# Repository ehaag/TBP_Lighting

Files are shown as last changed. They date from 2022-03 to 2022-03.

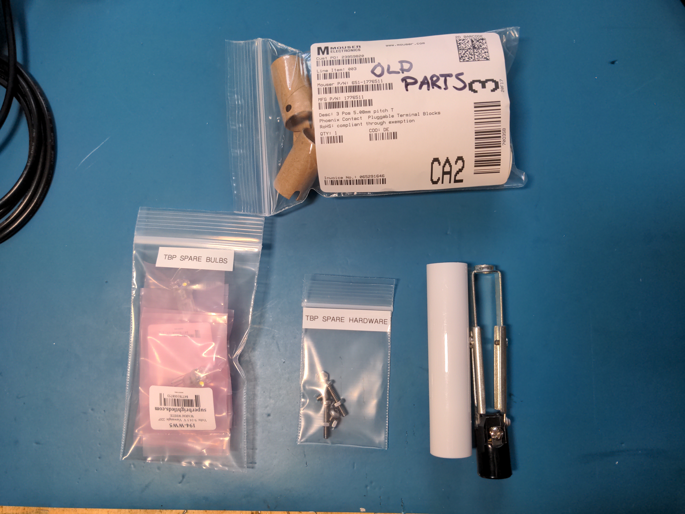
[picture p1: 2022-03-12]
img/Acc_PartsBags.jpg

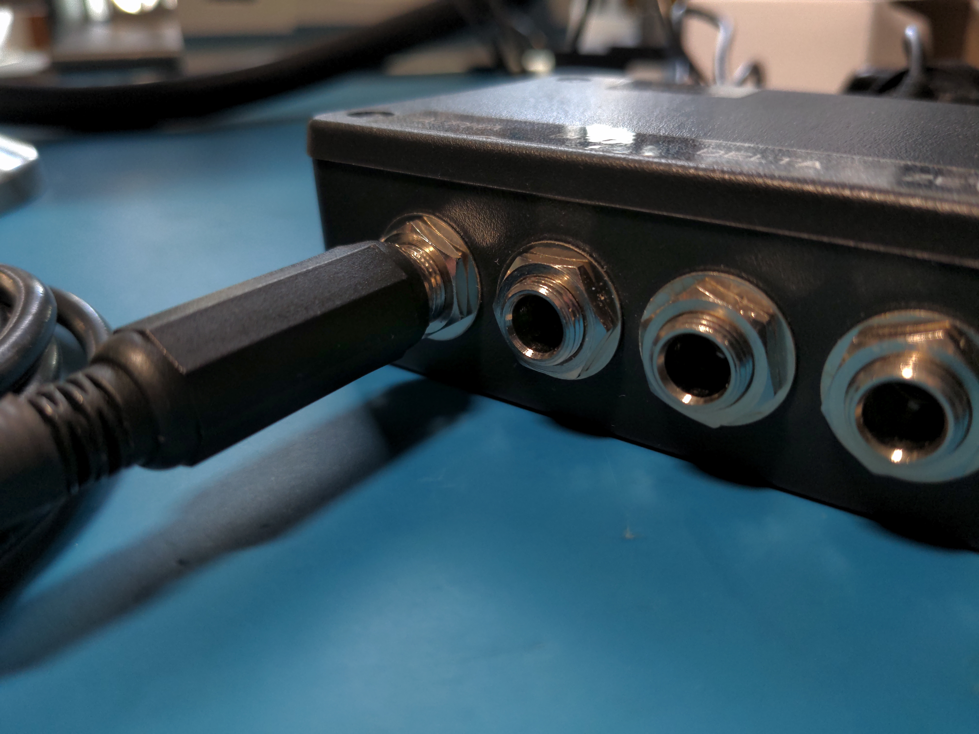
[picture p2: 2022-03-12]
img/Ctrl_LampPlugged.jpg

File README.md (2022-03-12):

# TBP_Lighting
**Ceremony lighting for Tau Beta Pi**

This repo holds the documentation for the Tau Beta Pi ceremony lighting revamp created by Erik Haag in Fall 2021. The main purpose of the project was to modernize some of the less-than-savory, officially sponsored hacks that were used to make the original system "safe". Main highlights include:
  * Moving from a mains-powered incandescent lamp to an LED lamp powered from low voltage DC
  * Improving the durability of the system through improved connectors, strain reliefs, and other parts
  * Custom PCB including overvoltage, reverse voltage, and overcurrent protection

The content here consists primarily of two sections. First, the user manual (i.e., the Wiki in the tab above) contains the basic information needed to operate the lighting system. Honestly, it's really pretty simple. There are lots of pictures. Don't be afraid. The other section pertains to the custom PCB that was designed for this project. It includes a schematic, a bill of materials, an assembly drawing, the KiCad project files, and the Gerbers for the board itself.

Finally, for any questions or concerns not explicitly addressed by the documents contained in this repository, please feel free to use the issue tracker associated with this repository. I have also included my U of M email address on the inside of the control unit's cover, in case I happen to miss anything here.

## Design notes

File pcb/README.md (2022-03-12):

PDFs provided for the protection board schematic and assembly drawing. CAD directory holds all design files. See the [Wiki](https://github.com/ehaag/TBP_Lighting/wiki/Home).

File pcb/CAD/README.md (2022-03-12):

CAD files for the protection board. Please see the associated [Wiki page](https://github.com/ehaag/TBP_Lighting/wiki/CAD).

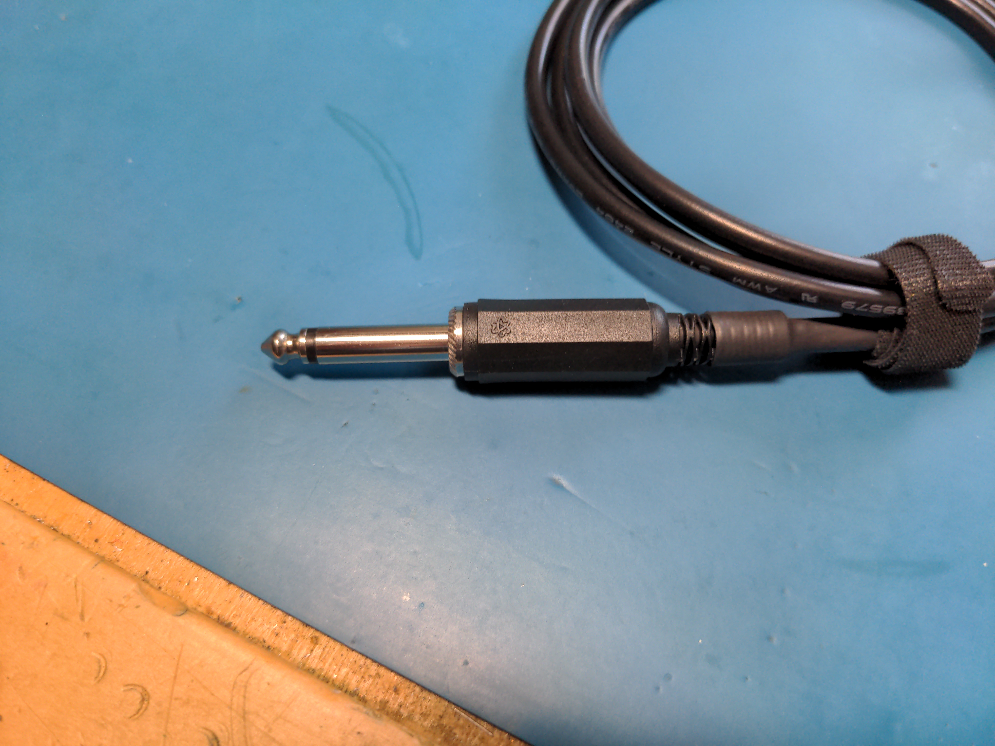
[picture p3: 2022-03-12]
img/Lamp_Plug.jpg

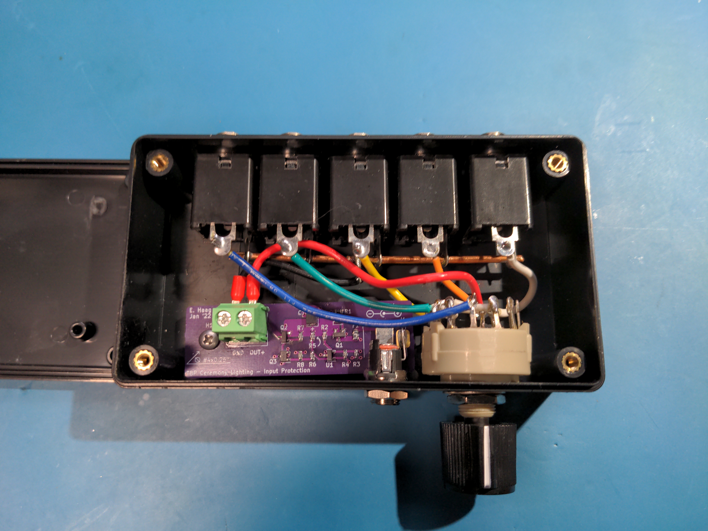
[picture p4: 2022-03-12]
img/Ctrl_OpenTop.jpg

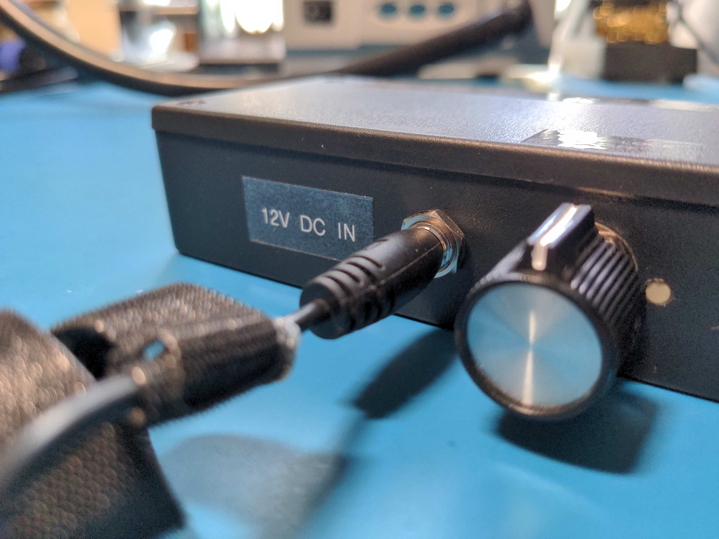
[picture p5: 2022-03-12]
img/Ctrl_DCPlugged.jpg

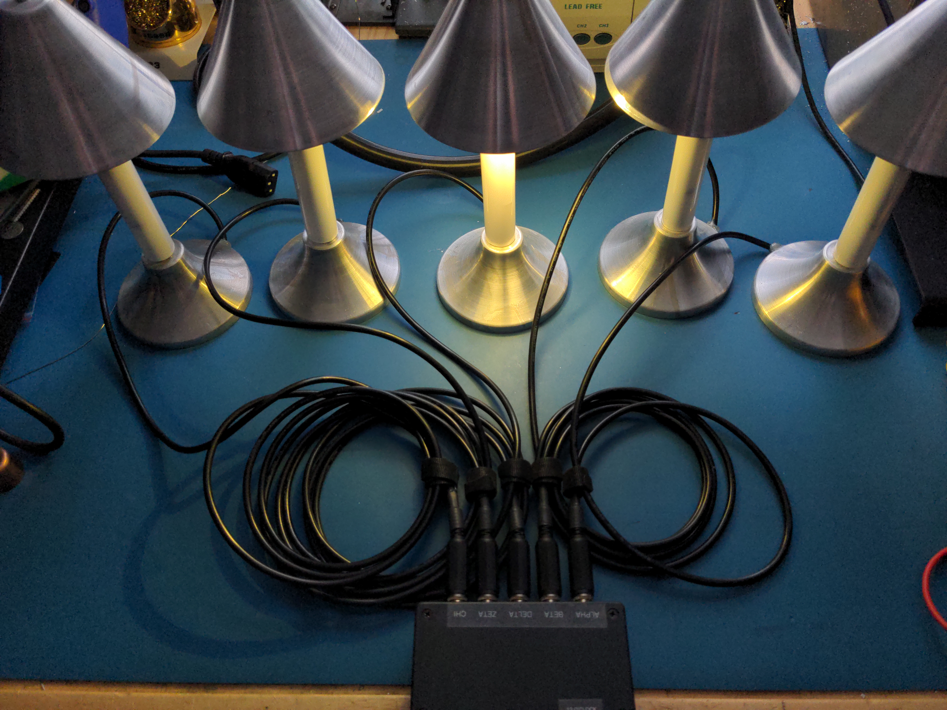
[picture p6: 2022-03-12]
img/Seq_Posn4.jpg

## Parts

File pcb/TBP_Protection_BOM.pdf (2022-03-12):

TBP_Protection

Page 1

Reference | Value | Manufacturer | Description | Footprint | Datasheet

# Protection Board Parts

C1 | 10u | Various | Tantalum polymer capacitor, 25V | Capacitor_Tantalum_SMD:CP_EIA-3528-12_Kemet-T | Generic
D1 | | Nexperia | Zener diode, 16V | Diode_SMD:D_SOD-323F | https://assets.nexperia.com/documents/data-sheet/PZUXB_SER.pdf
F1 | | Littelfuse | PTC fuse, 100mA | Fuse:Fuse_0805_2012Metric | https://www.littelfuse.com/~/media/electronics/datasheets/resettable_ptcs/littelfuse_ptc_0805l_datasheet.pdf.pdf
J1 | PJ-066B | CUI | 2.5x5.5mm DC barrel jack, panel mount | user_Connector:BarrelJack_CUI_PJ-066 | https://www.cuidevices.com/product/resource/pj-066a.pdf
J2 | MKDS | Phoenix Contact | MPN 1711725, 5.08mm, 2 position terminal block | TerminalBlock_Phoenix:TerminalBlock_Phoenix_MKDS-1,5-2-5.08_1x02_P5.08mm_Horizontal | https://media.digikey.com/pdf/Data%20Sheets/Phoenix%20Contact%20PDFs/1711725.pdf
Q1, Q2 | Si2369DS | Vishay | 30V P-channel MOSFET | Package_TO_SOT_SMD:SOT-23 | http://www.vishay.com/docs/62865/si2369d.pdf
Q3 | AO3404A | Alpha Omega Semi | 30V N-channel MOSFET | Package_TO_SOT_SMD:SOT-23 | http://aosmd.com/pdfs/datasheet/AO3404A.pdf
R1 | 100k | Various | Metal film resistor, 1% tolerance, 100ppm/degC | Resistor_SMD:R_0603_1608Metric | Generic
R2 | 33k | Various | Metal film resistor, 1% tolerance, 100ppm/degC | Resistor_SMD:R_0603_1608Metric | Generic
R3 | 6k8 | Various | Metal film resistor, 1% tolerance, 100ppm/degC | Resistor_SMD:R_0603_1608Metric | Generic
R4 | 330k | Various | Metal film resistor, 1% tolerance, 100ppm/degC | Resistor_SMD:R_0603_1608Metric | Generic
R5, R7 | 10k | Various | Metal film resistor, 1% tolerance, 100ppm/degC | Resistor_SMD:R_0603_1608Metric | Generic
R6 | 47k | Various | Metal film resistor, 1% tolerance, 100ppm/degC | Resistor_SMD:R_0603_1608Metric | Generic
R8 | 27k | Various | Metal film resistor, 1% tolerance, 100ppm/degC | Resistor_SMD:R_0603_1608Metric | Generic
U1 | ATL431DBZ | Texas Instruments | Adjustable voltage reference | Package_TO_SOT_SMD:SOT-23 | http://www.ti.com/lit/ds/symlink/atl431.pdf

# Other Control Unit Parts

| 111x | Switchcraft | ¼” mono jack, panel mount | N/A | https://www.switchcraft.com/Drawings/110x-m110x_series_cd.pdf
| 16-00031 | Tensility | 12V, 6W, AC-DC wall adapter | N/A | http://www.tensility.com/pdffiles/16-00031.pdf
| 1591XXBBK | Hammond | Black ABS project box | N/A | http://www.hammondmfg.com/pdf/1591XXB.pdf
| KC52A13.001NLS | E-Switch | 12 position rotary switch, single pole | N/A | https://sten-eswitch-13110800-production.s3.amazonaws.com/system/asset/product_line/data_sheet/105/KC.pdf

# Lamp Parts

| 4833.1210 | Schurter | ¼” mono plug, free hanging | N/A | https://www.schurter.com/en/datasheet/typ_4833.1210.pdf
| 30-00686 | Tensility | 20 AWG, 2 conductor cable | N/A | http://www.tensility.com/pdffiles/30-00686.pdf
| T3.25-SW | SuperBrightLEDs | T3.25 wedge base socket, wired | N/A | https://www.superbrightleds.com/moreinfo/vehicle-bulb-sockets-adapters/t325-wedge-base-socket-wired/1150/2737/
| 194-WW5 | SuperBrightLEDs | Miniature wedge, 30 lumens, warm white | N/A | https://www.superbrightleds.com/moreinfo/miniature-and-subminiature-bulbs/194-led-landscape-light-bulb-5-led-miniature-wedge-retrofit-30-lumens/3308/9892/

PZU16B2

0805L010/24YR

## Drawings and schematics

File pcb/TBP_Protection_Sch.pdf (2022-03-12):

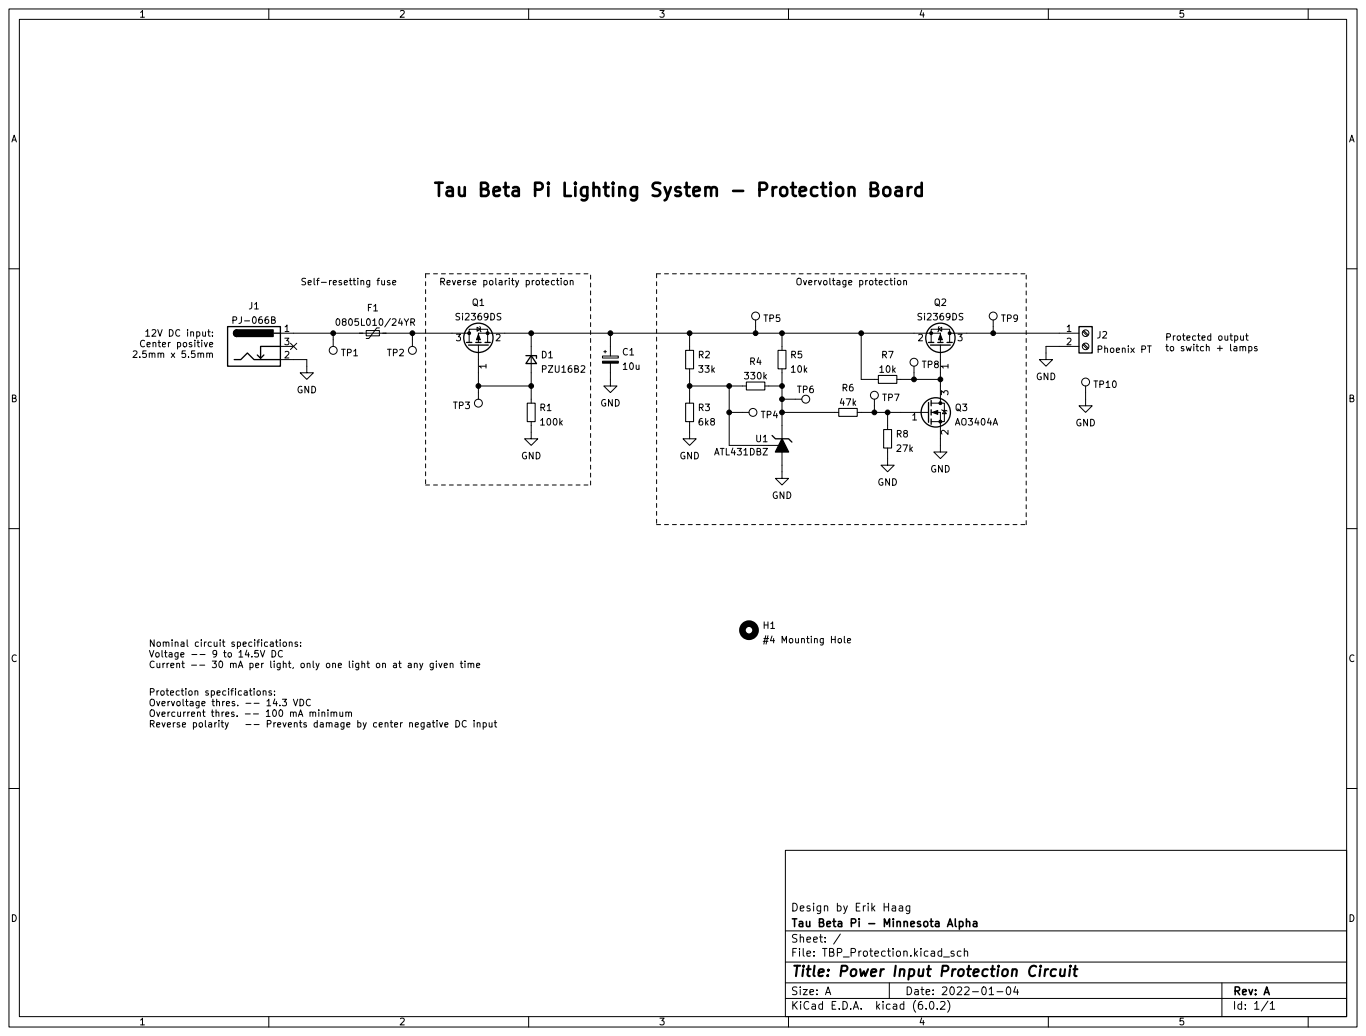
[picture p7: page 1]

Tau Beta Pi Lighting System - Protection Board

Nominal circuit specifications:
Voltage -- 9 to 14.5V DC
Current -- 30 mA per light, only one light on at any given time

Protection specifications:
Overvoltage thres. -- 14.3 VDC Overcurrent thres. -- 100 mA minimum

Reverse polarity -- Prevents damage by center negative DC input

File: TBP_Protection.kicad_sch Sheet: / Tau Beta Pi - Minnesota Alpha

Id: 1/1 Title: Power Input Protection Circuit

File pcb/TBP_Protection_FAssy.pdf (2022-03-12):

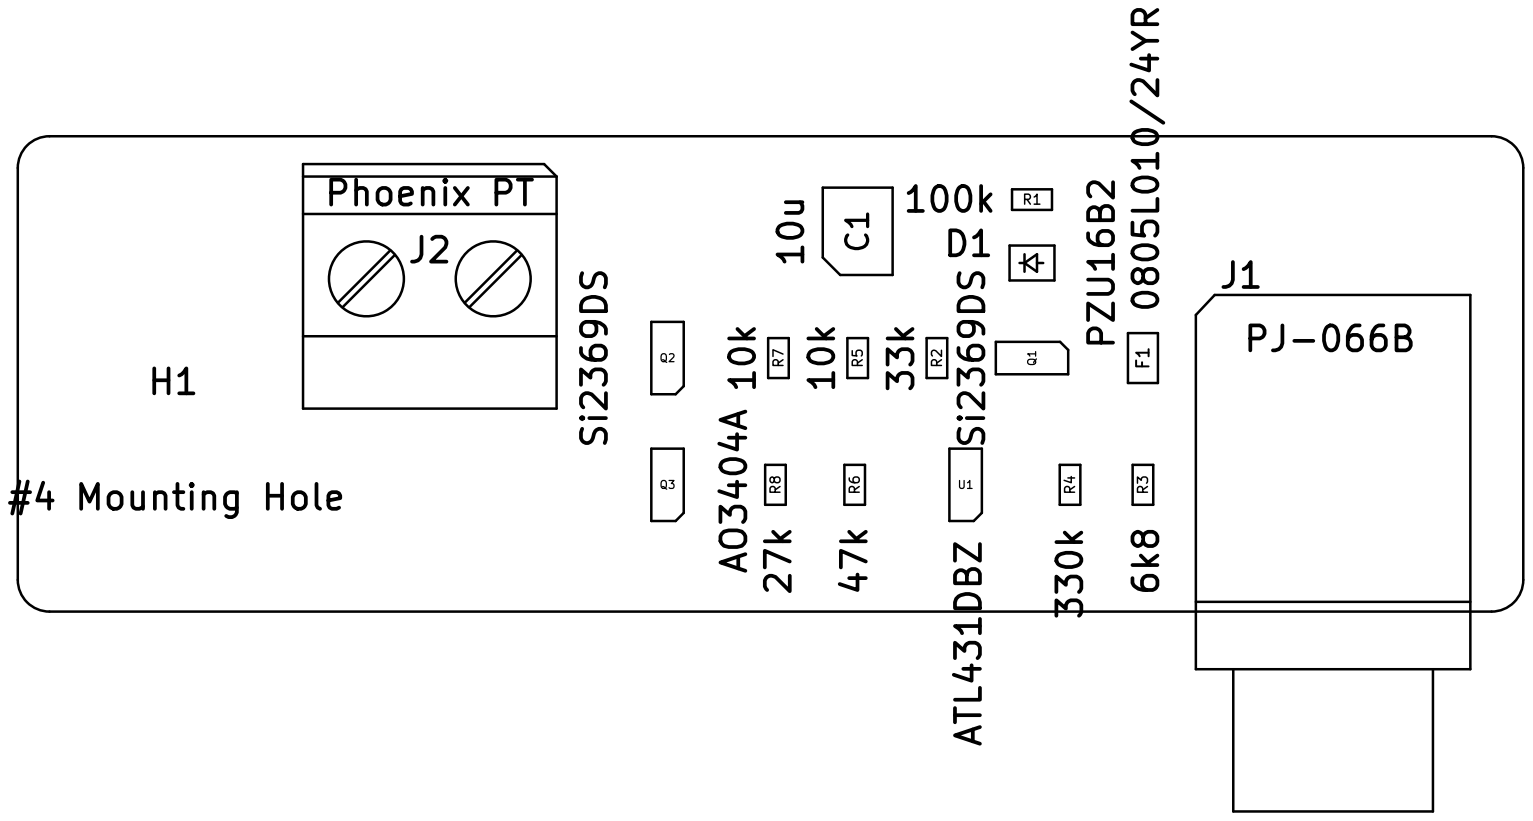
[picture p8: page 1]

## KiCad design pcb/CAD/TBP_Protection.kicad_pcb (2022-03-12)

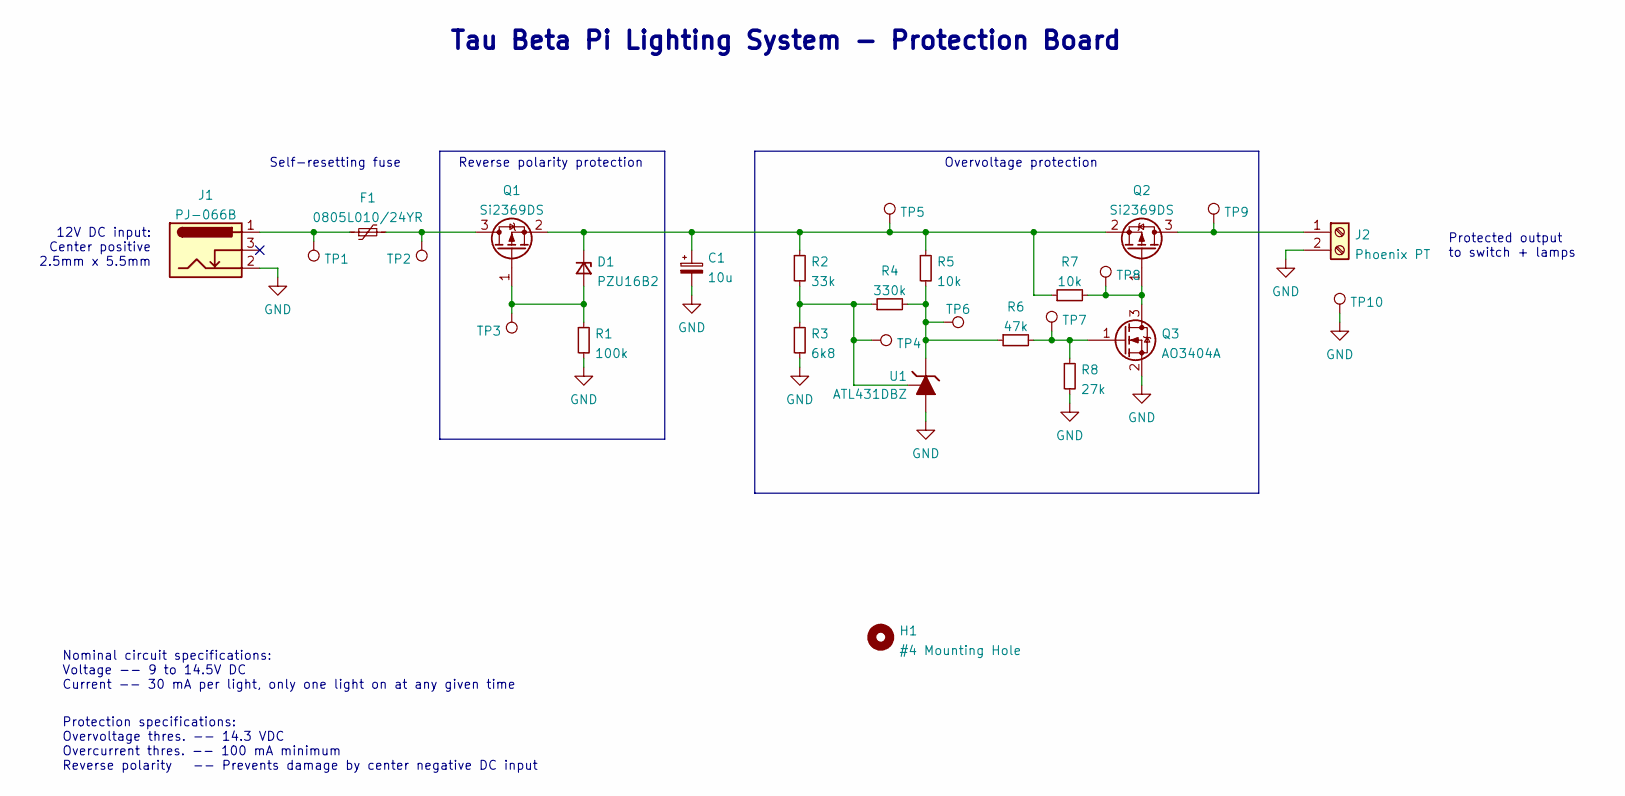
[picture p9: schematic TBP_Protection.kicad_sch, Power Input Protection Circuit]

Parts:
C1: 10u; CP_EIA-3528-12_Kemet-T
D1: ‎PZU16B2; D_SOD-323F
F1: ‎0805L010/24YR‎; Fuse_0805_2012Metric
H1: #4 Mounting Hole; MountingHole_3.5mm
J1: PJ-066B; BarrelJack_CUI_PJ-066A
J2: Phoenix PT; TerminalBlock_Phoenix_MKDS-1,5-2-5.08_1x02_P5.08mm_Horizont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
Q1, Q2: Si2369DS; SOT-23
Q3: AO3404A; SOT-23
R1: 100k; R_0603_1608Metric
R2: 33k; R_0603_1608Metric
R3: 6k8; R_0603_1608Metric
R4: 330k; R_0603_1608Metric
R5, R7: 10k; R_0603_1608Metric
R6: 47k; R_0603_1608Metric
R8: 27k; R_0603_1608Metric
TP1, TP2, TP3, TP4, TP5, TP6, TP7, TP8, TP9, TP10: TestPoint_Small; TestPoint_Pad_D1.5mm
U1: ATL431DBZ; SOT-23

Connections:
GND: C1.2, J1.2, J2.2, Q3.2 (S), R1.2, R3.2, R8.2, TP10.1, U1.3 (A)
unnamed: C1.1, D1.1 (K), Q1.2 (S), Q2.2 (S), R2.1, R5.1, R7.1, TP5.1
unnamed: D1.2 (A), Q1.1 (G), R1.1, TP3.1
unnamed: F1.1, J1.1, TP1.1
unnamed: F1.2, Q1.3 (D), TP2.1
unnamed: J2.1, Q2.3 (D), TP9.1
unnamed: Q2.1 (G), Q3.3 (D), R7.2, TP8.1
unnamed: Q3.1 (G), R6.2, R8.1, TP7.1
unnamed: R2.2, R3.1, R4.1, TP4.1, U1.2 (REF)
unnamed: R4.2, R5.2, R6.1, TP6.1, U1.1 (K)

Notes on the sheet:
Overvoltage protection
12V DC input: Center positive 2.5mm x 5.5mm
Nominal circuit specifications: Voltage -- 9 to 14.5V DC Current -- 30 mA per light, only one light on at any given time
Protected output to switch + lamps
Reverse polarity protection
Protection specifications: Overvoltage thres. -- 14.3 VDC Overcurrent thres. -- 100 mA minimum Reverse polarity -- Prevents damage by center negative DC input
Tau Beta Pi Lighting System - Protection Board
Self-resetting fuse

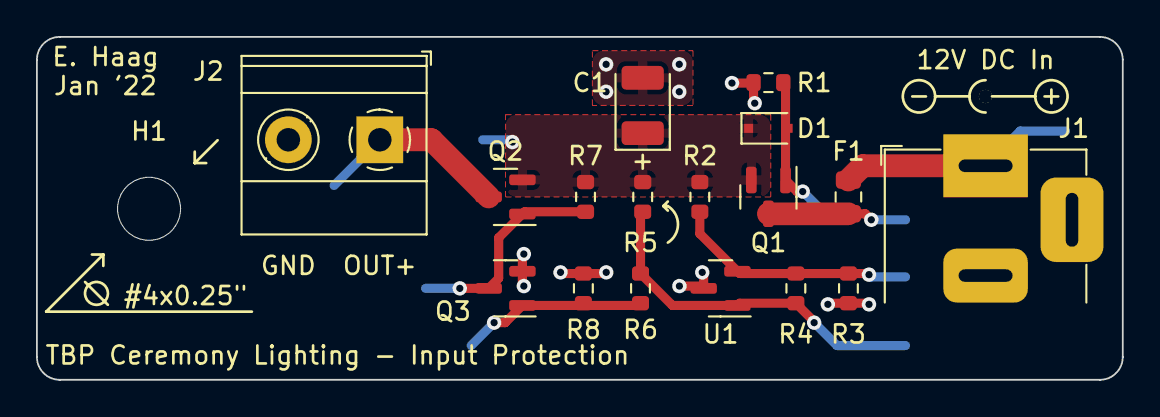
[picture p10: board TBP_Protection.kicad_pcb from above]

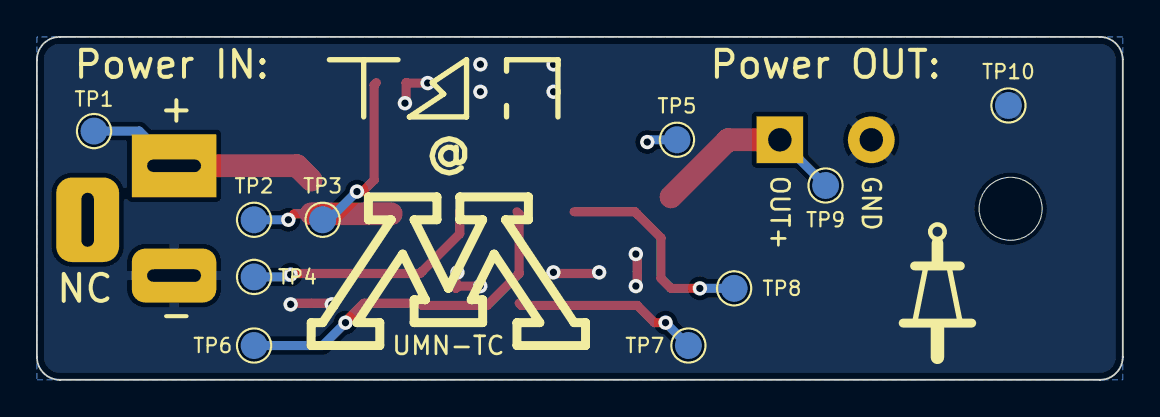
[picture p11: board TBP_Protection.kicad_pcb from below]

Board: 2 copper layers, 60.3 x 19.1 mm, 28 parts (10 on the bottom side), 10 nets.

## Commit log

2022-03-12 Added PCB files
    [TBP_Protection.kicad_pcb, TBP_Protection.kicad_sch]
2022-03-12 Added BOM
2022-03-13 Remove KiCad project file
